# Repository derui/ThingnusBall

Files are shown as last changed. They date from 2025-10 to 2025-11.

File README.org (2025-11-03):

* ThingnusBall
This is a split keyboard having these features:

- ZMK firmware
- 3D printed keyboard case & track ball case
  - Track ball case can set on keyboard with magnets
- thin body
  - bottom of case to keytop is less than *20mm*
  - Fot this, suppoted socket is chok v2 only
- Encoder and 25mm track ball
  - You can manage behavior with ZMK
- all wireless
- able to use rechageable AA battery
  - I use eneloop for this

* Bill Of Materials

| Name                                   | Qty |
|----------------------------------------+-----|
| SeeedStudio XIAO nRF52480              |   2 |
| AA battery holder                      |   2 |
| M3 nut                                 |   8 |
| M3 screw                               |   8 |
| [[https://github.com/snize/BOB-PMW3610-SEIBOKU][SEIBOKU]]                                |   1 |
| AE-XCL102D333CR-G                      |   2 |
| 1N4148W                                |  64 |
| Choc V2 Socket                         |  42 |
| Rotally Encoder (ALPS EC12 compatible) |   1 |
| SS-12D01G3                             |   2 |

* LICENSE
MIT

** LISENCE note
This keyboard uses Seeed Studio's XIAO nRF52480 kicad symbol and footprint. There are licensed under MIT that they written in [[https://wiki.seeedstudio.com/ja/License/][here]].

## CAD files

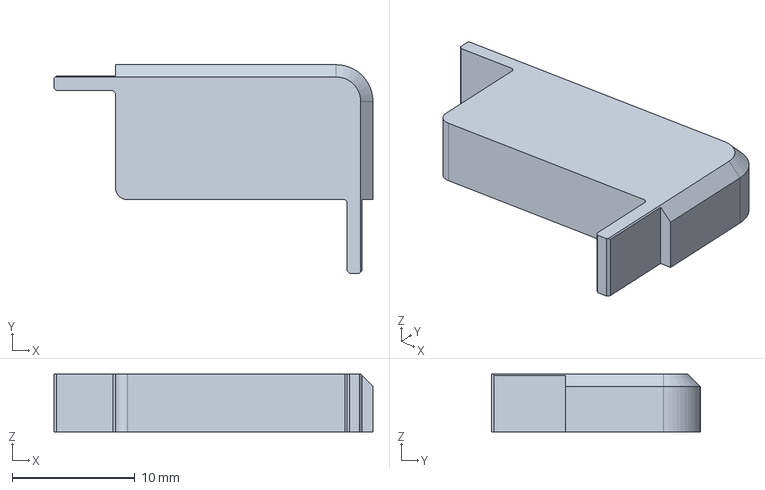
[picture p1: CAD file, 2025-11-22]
micom-cover.FCStd
26.0 x 17.0 x 4.70 mm

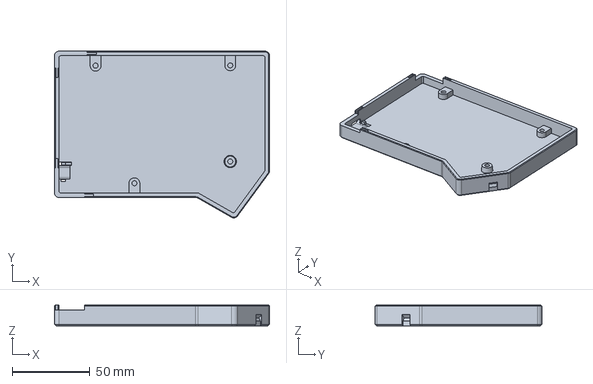
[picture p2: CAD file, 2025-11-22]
case.FCStd
138.6 x 107.6 x 13.3 mm

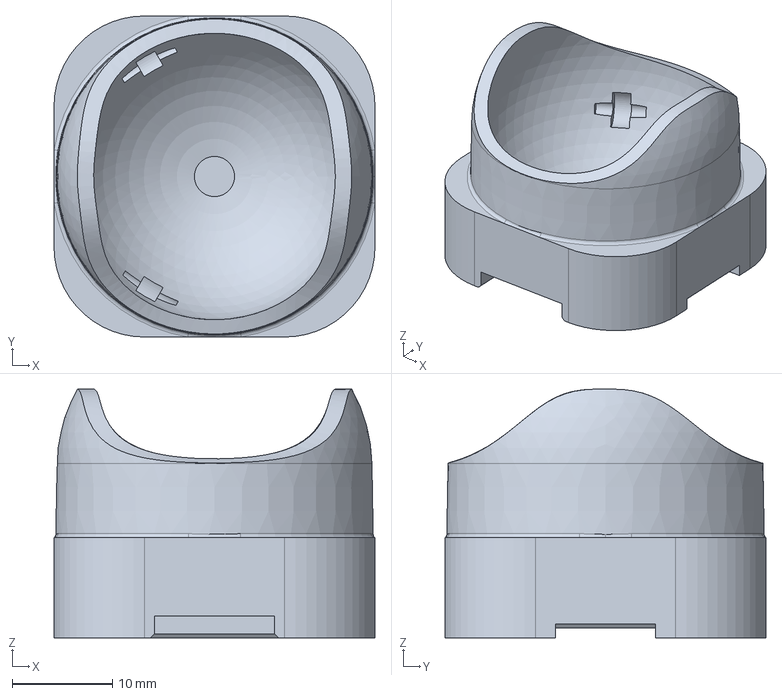
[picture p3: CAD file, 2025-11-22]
track-ball.FCStd
32.0 x 32.0 x 24.8 mm

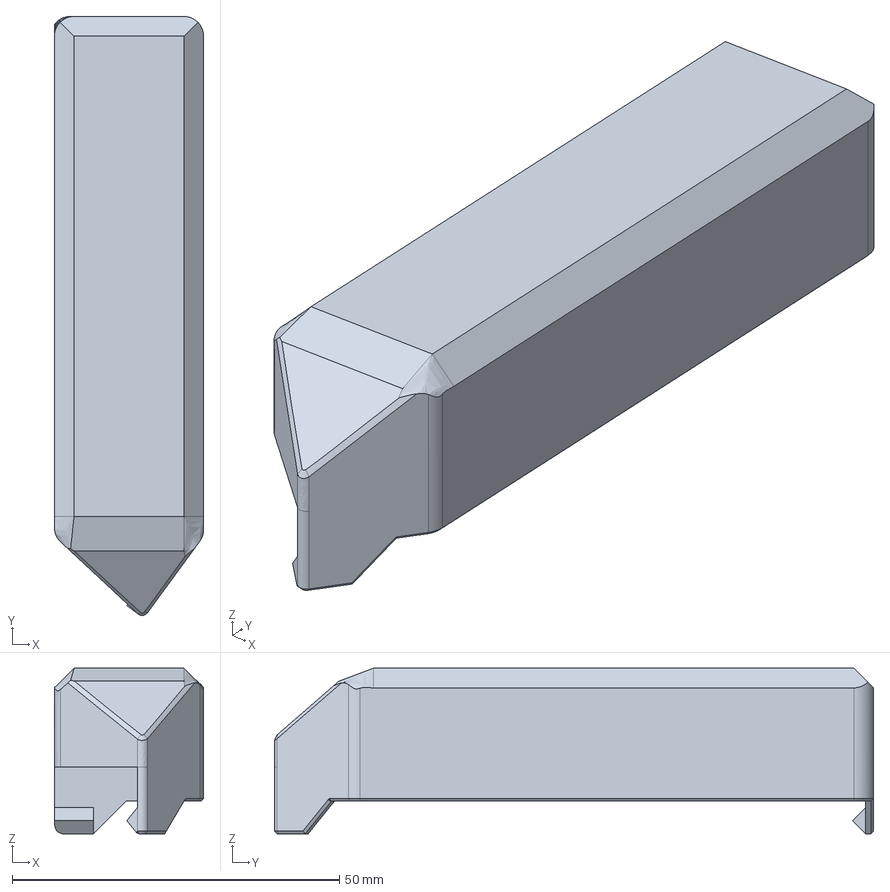
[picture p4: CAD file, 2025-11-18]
battery-cover.FCStd
22.8 x 91.6 x 25.3 mm

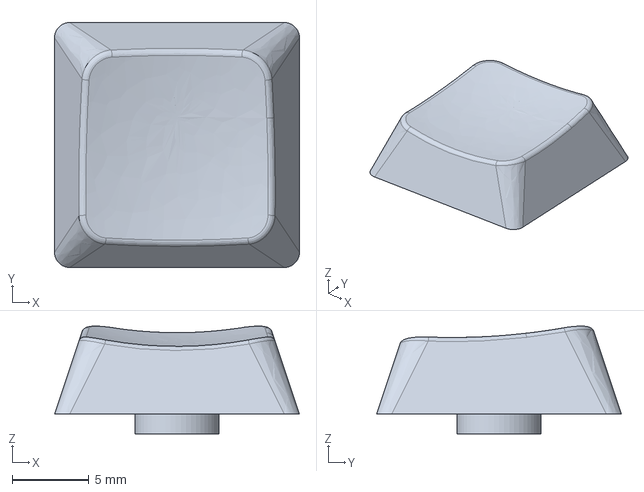
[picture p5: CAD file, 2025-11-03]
key-cap.FCStd
16.0 x 16.0 x 7.04 mm

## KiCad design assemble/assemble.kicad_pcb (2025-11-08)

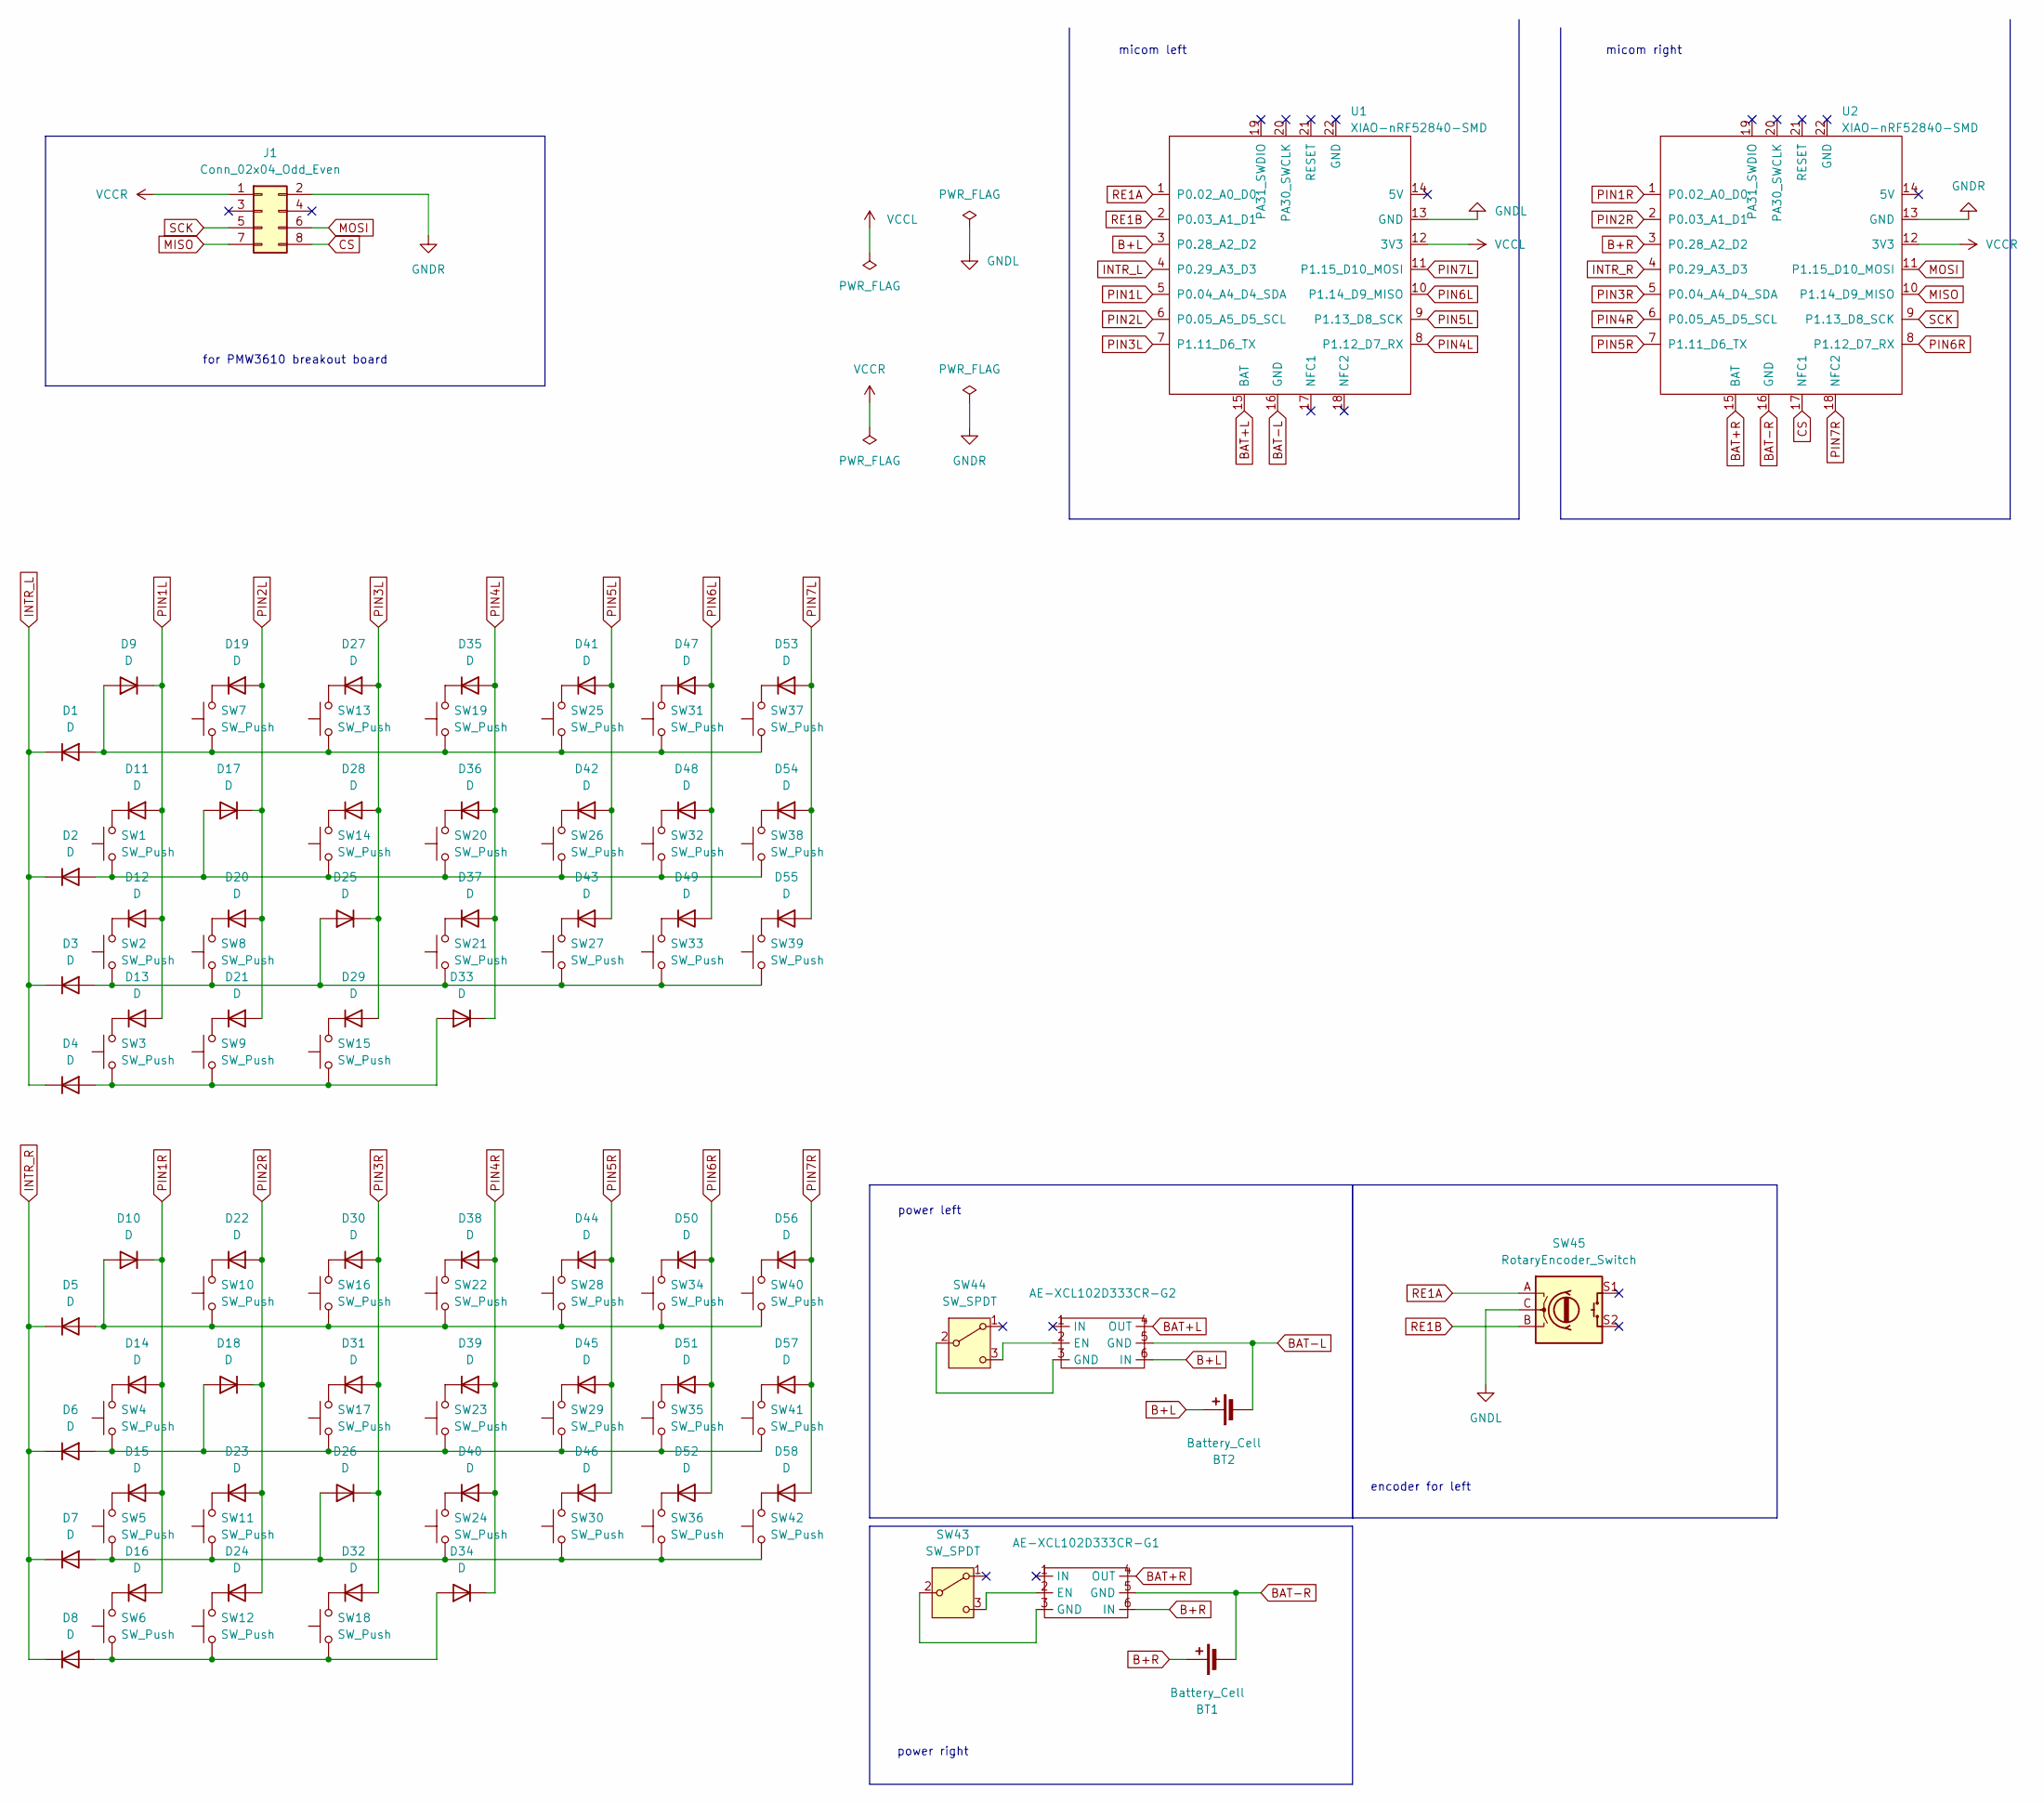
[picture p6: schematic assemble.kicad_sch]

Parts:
AE-XCL102D333CR-G1, AE-XCL102D333CR-G2: AE-XCL102D333CR-G
BT1, BT2: Battery_Cell; BatteryHolder_Keystone_2460_1xAA
D1, D2, D3, D4, D5, D6, D7, D8, D9, D10, D11, D12, D13, D14, D15, D16, D17, D18, D19, D20, D21, D22, D23, D24, D25, D26, D27, D28, D29, D30, D31, D32, D33, D34, D35, D36, D37, D38, D39, D40, D41, D42, D43, D44, D45, D46, D47, D48, D49, D50, D51, D52, D53, D54, D55, D56, D57, D58: D; Diode_SMD
J1: Conn_02x04_Odd_Even; PinSocket_2x04_P2.54mm_Vertical
SW1, SW2, SW3, SW4, SW5, SW6, SW7, SW8, SW9, SW10, SW11, SW12, SW13, SW14, SW15, SW16, SW17, SW18, SW19, SW20, SW21, SW22, SW23, SW24, SW25, SW26, SW27, SW28, SW29, SW30, SW31, SW32, SW33, SW34, SW35, SW36, SW37, SW38, SW39, SW40, SW41, SW42: SW_Push; Choc_v2_Hotswap_1u_16.6
SW43, SW44: SW_SPDT; TGSW_MSK-12D19
SW45: RotaryEncoder_Switch; RotaryEncoder_EC12E
U1, U2: XIAO-nRF52840-SMD

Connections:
B+L: AE-XCL102D333CR-G2.6 (IN), BT2.1 (+), U1.3 (P0.28_A2_D2)
B+R: AE-XCL102D333CR-G1.6 (IN), BT1.1 (+), U2.3 (P0.28_A2_D2)
BAT+L: AE-XCL102D333CR-G2.4 (OUT), U1.15 (BAT)
BAT+R: AE-XCL102D333CR-G1.4 (OUT), U2.15 (BAT)
BAT-L: AE-XCL102D333CR-G2.5 (GND), BT2.2 (-), U1.16 (GND)
BAT-R: AE-XCL102D333CR-G1.5 (GND), BT1.2 (-), U2.16 (GND)
CS: J1.8, U2.17 (NFC1)
GNDL: SW45.C, U1.13 (GND)
GNDR: J1.2, U2.13 (GND)
INTR_L: D1.1 (K), D2.1 (K), D3.1 (K), D4.1 (K), U1.4 (P0.29_A3_D3)
INTR_R: D5.1 (K), D6.1 (K), D7.1 (K), D8.1 (K), U2.4 (P0.29_A3_D3)
MISO: J1.7, U2.10 (P1.14_D9_MISO)
MOSI: J1.6, U2.11 (P1.15_D10_MOSI)
unnamed: AE-XCL102D333CR-G1.2 (EN), SW43.3 (C)
unnamed: AE-XCL102D333CR-G2.2 (EN), SW44.3 (C)
unnamed: D1.2 (A), D9.2 (A), SW7.1, SW13.1, SW19.1, SW25.1, SW31.1, SW37.1
unnamed: D5.2 (A), D10.2 (A), SW10.1, SW16.1, SW22.1, SW28.1, SW34.1, SW40.1
unnamed: D11.1 (K), SW1.2
unnamed: D12.1 (K), SW2.2
unnamed: D13.1 (K), SW3.2
unnamed: D14.1 (K), SW4.2
unnamed: D15.1 (K), SW5.2
unnamed: D16.1 (K), SW6.2
unnamed: D2.2 (A), D17.2 (A), SW1.1, SW14.1, SW20.1, SW26.1, SW32.1, SW38.1
unnamed: D6.2 (A), D18.2 (A), SW4.1, SW17.1, SW23.1, SW29.1, SW35.1, SW41.1
unnamed: D19.1 (K), SW7.2
unnamed: D20.1 (K), SW8.2
unnamed: D21.1 (K), SW9.2
unnamed: D22.1 (K), SW10.2
unnamed: D23.1 (K), SW11.2
unnamed: D24.1 (K), SW12.2
unnamed: D3.2 (A), D25.2 (A), SW2.1, SW8.1, SW21.1, SW27.1, SW33.1, SW39.1
unnamed: D7.2 (A), D26.2 (A), SW5.1, SW11.1, SW24.1, SW30.1, SW36.1, SW42.1
unnamed: D27.1 (K), SW13.2
unnamed: D28.1 (K), SW14.2
unnamed: D29.1 (K), SW15.2
unnamed: D30.1 (K), SW16.2
unnamed: D31.1 (K), SW17.2
unnamed: D32.1 (K), SW18.2
unnamed: D4.2 (A), D33.2 (A), SW3.1, SW9.1, SW15.1
unnamed: D8.2 (A), D34.2 (A), SW6.1, SW12.1, SW18.1
unnamed: D35.1 (K), SW19.2
unnamed: D36.1 (K), SW20.2
unnamed: D37.1 (K), SW21.2
unnamed: D38.1 (K), SW22.2
unnamed: D39.1 (K), SW23.2
unnamed: D40.1 (K), SW24.2
unnamed: D41.1 (K), SW25.2
unnamed: D42.1 (K), SW26.2
unnamed: D43.1 (K), SW27.2
unnamed: D44.1 (K), SW28.2
unnamed: D45.1 (K), SW29.2
unnamed: D46.1 (K), SW30.2
unnamed: D47.1 (K), SW31.2
unnamed: D48.1 (K), SW32.2
unnamed: D49.1 (K), SW33.2
unnamed: D50.1 (K), SW34.2
unnamed: D51.1 (K), SW35.2
unnamed: D52.1 (K), SW36.2
unnamed: D53.1 (K), SW37.2
unnamed: D54.1 (K), SW38.2
unnamed: D55.1 (K), SW39.2
unnamed: D56.1 (K), SW40.2
unnamed: D57.1 (K), SW41.2
unnamed: D58.1 (K), SW42.2
unnamed: AE-XCL102D333CR-G1.3 (GND), SW43.2 (B)
unnamed: AE-XCL102D333CR-G2.3 (GND), SW44.2 (B)
PIN1L: D9.1 (K), D11.2 (A), D12.2 (A), D13.2 (A), U1.5 (P0.04_A4_D4_SDA)
PIN1R: D10.1 (K), D14.2 (A), D15.2 (A), D16.2 (A), U2.1 (P0.02_A0_D0)
PIN2L: D17.1 (K), D19.2 (A), D20.2 (A), D21.2 (A), U1.6 (P0.05_A5_D5_SCL)
PIN2R: D18.1 (K), D22.2 (A), D23.2 (A), D24.2 (A), U2.2 (P0.03_A1_D1)
PIN3L: D25.1 (K), D27.2 (A), D28.2 (A), D29.2 (A), U1.7 (P1.11_D6_TX)
PIN3R: D26.1 (K), D30.2 (A), D31.2 (A), D32.2 (A), U2.5 (P0.04_A4_D4_SDA)
PIN4L: D33.1 (K), D35.2 (A), D36.2 (A), D37.2 (A), U1.8 (P1.12_D7_RX)
PIN4R: D34.1 (K), D38.2 (A), D39.2 (A), D40.2 (A), U2.6 (P0.05_A5_D5_SCL)
PIN5L: D41.2 (A), D42.2 (A), D43.2 (A), U1.9 (P1.13_D8_SCK)
PIN5R: D44.2 (A), D45.2 (A), D46.2 (A), U2.7 (P1.11_D6_TX)
PIN6L: D47.2 (A), D48.2 (A), D49.2 (A), U1.10 (P1.14_D9_MISO)
PIN6R: D50.2 (A), D51.2 (A), D52.2 (A), U2.8 (P1.12_D7_RX)
PIN7L: D53.2 (A), D54.2 (A), D55.2 (A), U1.11 (P1.15_D10_MOSI)
PIN7R: D56.2 (A), D57.2 (A), D58.2 (A), U2.18 (NFC2)
RE1A: SW45.A, U1.1 (P0.02_A0_D0)
RE1B: SW45.B, U1.2 (P0.03_A1_D1)
SCK: J1.5, U2.9 (P1.13_D8_SCK)
VCCL: U1.12 (3V3)
VCCR: J1.1, U2.12 (3V3)

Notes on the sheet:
for PMW3610 breakout board
encoder for left
micom right
power left
power right
micom left

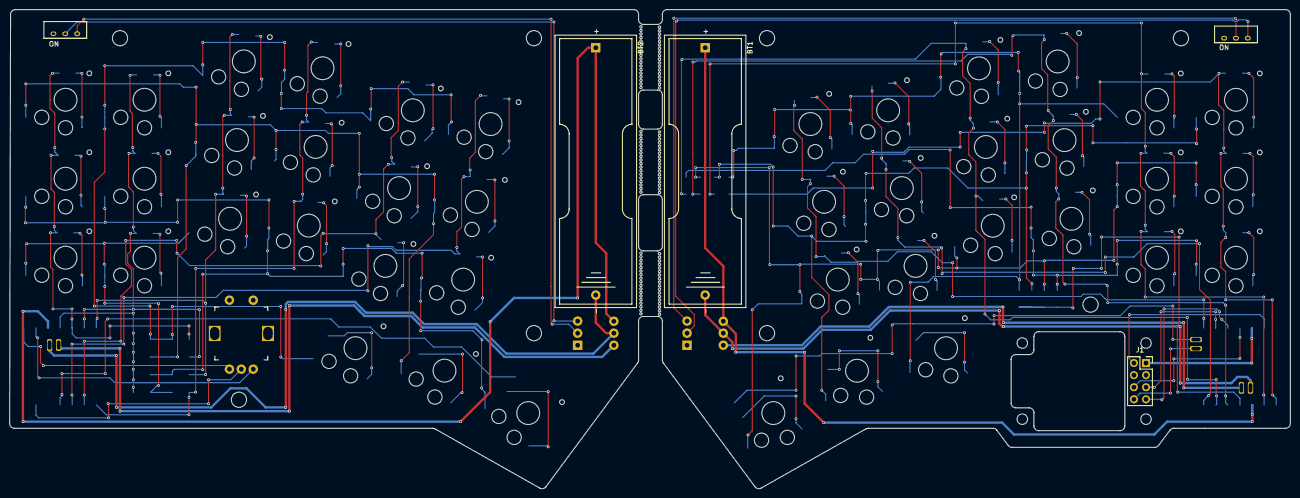
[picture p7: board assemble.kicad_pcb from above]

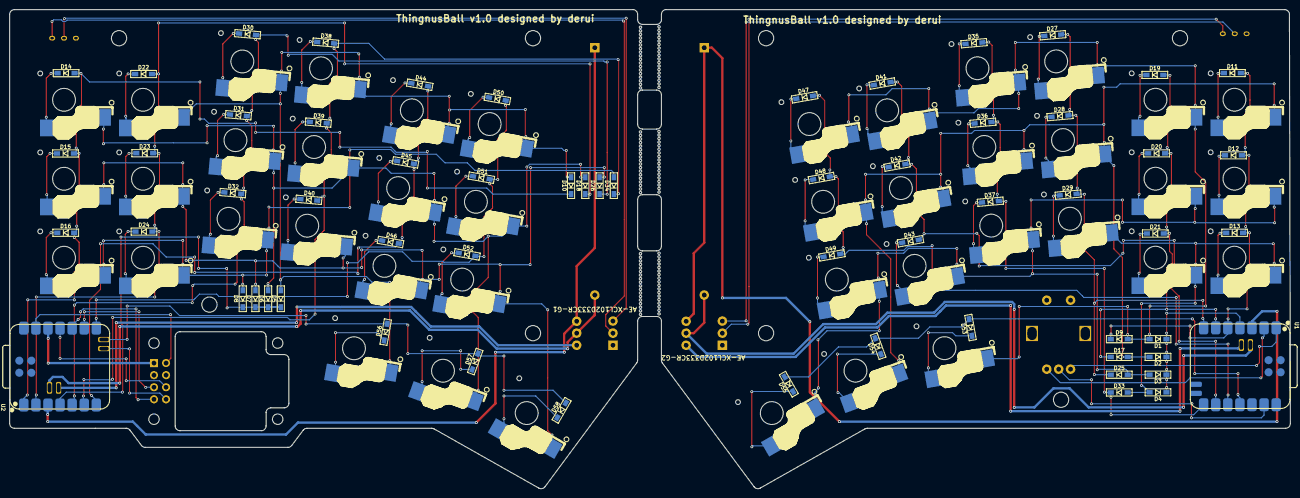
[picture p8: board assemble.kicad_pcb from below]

Board: 2 copper layers, 269.2 x 100.7 mm, 140 parts (4 on the bottom side), 85 nets.

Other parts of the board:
Ref**: Val**; Mouse_Bite_Hole
Ref**#2, Ref**#3, Ref**#5, Ref**#6, Ref**#7, Ref**#9, Ref**#17, Ref**#28: Val**; m3_Screw_Hole_EdgeCuts
Ref**#4, Ref**#10, Ref**#12, Ref**#13, Ref**#14, Ref**#15, Ref**#16, Ref**#18, Ref**#19, Ref**#20, Ref**#21, Ref**#22, Ref**#24, Ref**#25, Ref**#27, Ref**#29, Ref**#30: Val**; Mouse_Bite_Hole
Ref**#8, Ref**#11, Ref**#23, Ref**#26: Val**; m2_Screw_Hole_EdgeCuts

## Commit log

2025-10-04 feat: WIP assemble
    [assemble.kicad_pcb, assemble.kicad_sch]
2025-10-11 feat: implement PCB
    [assemble.kicad_pcb]
2025-10-13 feat: finish implement PCB
    [assemble.kicad_pcb, assemble.kicad_sch]
2025-10-13 feat: add switch plate
    [switch_plate.kicad_pcb]
2025-10-26 fix: change position
    [assemble.kicad_pcb, assemble.kicad_sch]
2025-10-27 feat: add bottom plate
    [bottom_plate.kicad_pcb, switch_plate.kicad_pcb]
2025-10-28 feat: add case model
    [battery-cover.FCStd, bottom_plate.kicad_pcb, case.FCStd]
2025-11-03 feat: change case and re-wired
    [assemble.kicad_pcb, assemble.kicad_sch, battery-cover.FCStd]
2025-11-03 feat: add key cap and trackball
    [key-cap.FCStd, track-ball.FCStd]
2025-11-03 [ci skip] docs: add BOM temporary
2025-11-08 fix: case problems
    [assemble.kicad_pcb, battery-cover.FCStd, track-ball.FCStd]
2025-11-18 fix: case and cover
    [battery-cover.FCStd, case.FCStd, track-ball.FCStd]
2025-11-22 fix: switch cover
    [case.FCStd, micom-cover.FCStd, track-ball.FCStd]
